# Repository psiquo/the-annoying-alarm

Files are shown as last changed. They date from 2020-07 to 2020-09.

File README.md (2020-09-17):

# The Annoying Alarm
The annoying alarm è una sveglia "intelligente" che una volta attivata si muove evitando gli ostacoli fino a quando non viene catturata e spenta.

L'orario della sveglia viene selzionata dall'utente mediante interfaccia web o mediante MQTT.

## Materiale utilizzato
- Arduino Mega
- Esp8266
- Active Buzzer
- 2x Powerbank
- 3x HC-SR04 
- L298N
- Bottone
- Set Macchina (Comprensivo di struttura e due motori DC)
- Batteria 9V

## Liberie Utilizzate
- [L298N](https://github.com/AndreaLombardo/L298N)
- [ESP8266Wifi](https://arduino-esp8266.readthedocs.io/en/latest/esp8266wifi/readme.html)
- [NTPClient](https://github.com/arduino-libraries/NTPClient)
- [Arduino-PID-Library](https://github.com/br3ttb/Arduino-PID-Library/)
- [WiFiUDP](https://github.com/esp8266/Arduino/blob/master/libraries/ESP8266WiFi/src/WiFiUdp.h)
- [Timezone](https://github.com/JChristensen/Timezone)
- [PubSubClient](https://github.com/knolleary/pubsubclient/)

## Circuito
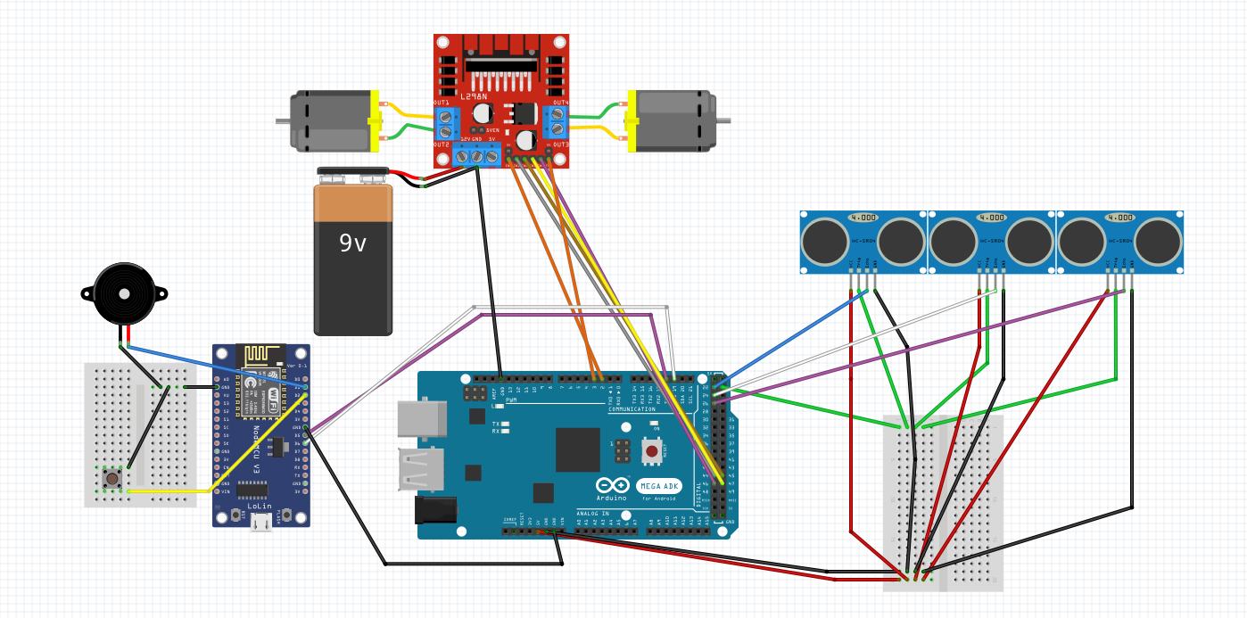
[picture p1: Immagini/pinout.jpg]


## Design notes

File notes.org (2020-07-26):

* Inbox
* Cablaggi
 - Rosso => Volt
 - Nero => Ground
 - Verde => Trigger
 - Blu => Echo Centrale
 - Viola => Echo Destra
 - Violetto => En2 Motore destro
 - Bianco => Echo Sinistra
 - Giallo => En1 Motore Sinistro
 - Blu => En2 Motore Sinistro
 - Grigio => En1 Motore Destro
 - Arancione => Enab Motori
* Pin Map
 - D0 => Trigger (OUT)
 - D1 => Echo centrale (IN)
 - D2 => Echo Destra (IN)
 - D3 => En2 Motore destro (se a 1 mentre en1 0 va in retro) (OUT)
 - D4 => Echo sinistra (IN)
 - D5 => En1 Motore sinistro (se a 1 mentre en 2 0 va avanti) (OUT)
 - D6 => En2 motore sinistro (tale quale D3) (OUT)
 - D7 => En1 motore destro (tale quale D5) (OUT)
 - D4 => Interrupt (si spera)

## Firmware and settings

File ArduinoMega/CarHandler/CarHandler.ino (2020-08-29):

#include "Constants.h"

bool led = true;
int target;

void setup() {
  // put your setup code here, to run once:
  pinMode(LED_BUILTIN,OUTPUT);
  setup_dist();
  setup_motor();
  setup_serial();
  Serial.begin(115200);
}

void loop() {
  handle_serial();
  if (enabled){
    drive();
  } else {
     motor_stop();
  }
}

void drive() {
    update_dist();
    dist = distance[1];
    fw_pid.Compute();
    go();
        
    if ( distance[1] < FORWARD_DISTANCE  and min(distance[0], distance[2]) > FORWARD_DISTANCE){
      motor_stop();
      if (distance[0] > distance[2]){
        target = distance[0];
        left(ROTATION_SPEED);
      } else {
        target = distance[2];
        right(ROTATION_SPEED);
      }
      do {
        update_dist();
      }while(distance[1] < max(target,30));
  
      motor_stop();
    } else if (distance[0] < SIDE_DISTANCE) {
      right(ROTATION_SPEED);
      do {
        update_dist();
      }while(distance[0] < max(30,distance[1]));
  
      motor_stop();
    } else if (distance[2] < SIDE_DISTANCE) {
      left(ROTATION_SPEED);
      do {
        update_dist();
      }while(distance[2] < max(distance[1],30));
    }
  }

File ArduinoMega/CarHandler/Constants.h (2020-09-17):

// Distance Module
//---Includes
#include <stdlib.h>
// --- Pins
/*const int*/ #define trigPin 23
const int echo[] = {22,24,26};

// --- Values
const int sensors = 3;
const int default_d_value = 200;
long duration;
double distance[sensors];
int tempDist;
double oldDistance[sensors];
int measures = 4;

//Motor Module
//---Includes
#include "L298N.h"
#include <PID_v1.h>
//---Pins
/* const int */ #define LEnab  2
/* const int */ #define REnab  3
/* const int */ #define LIn1 44
/* const int */ #define LIn2 45
/* const int */ #define RIn1 46
/* const int */ #define RIn2 47

//---Values
#define MAX_SPEED 200
#define MIN_SPEED 90//130
#define ROTATION_SPEED 90

#define FORWARD_DISTANCE 20
#define SIDE_DISTANCE 20

#define Kp 1.6//2.
#define Ki 9.6
#define Kd 0.//02

double dist,setPoint_fw = 70, output_speed=0;

L298N Left(LEnab, LIn1, LIn2);
L298N Right(REnab,RIn1,RIn2);

PID fw_pid(&dist, &output_speed, &setPoint_fw, Kp,Ki,Kd,REVERSE);

//Serial Module
//---Values
bool enabled = false;

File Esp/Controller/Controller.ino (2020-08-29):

#include "Constants.h"

bool led = true;

void log_msg(String msg) {
  Serial.println(msg);
  mqtt_print(msg);
}

void setup() {
  // put your setup code here, to run once:
  Serial.begin(115200);
  pinMode(LED_BUILTIN,OUTPUT);
  setup_wifi();
  setup_time();
  setup_alarm();
  setup_mqtt();
  setup_serial();
  setup_http();
}

void loop() {
  // put your main code here, to run repeatedly:
  mqtt_handle();
  check_alarm();
  handle_serial();
  if(alarm_active) {
    digitalWrite(alarmPin,HIGH);
  } else {    
    digitalWrite(alarmPin,LOW);
  }
  digitalWrite(LED_BUILTIN,led = not led);
  delay(1000);
}

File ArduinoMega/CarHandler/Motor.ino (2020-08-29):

void setup_motor() {
   pinMode(REnab,OUTPUT);
  pinMode(LEnab,OUTPUT);
  pinMode(LIn1, OUTPUT);
  pinMode(LIn2, OUTPUT);
  pinMode(RIn1, OUTPUT);
  pinMode(RIn1, OUTPUT);

  fw_pid.SetOutputLimits(MIN_SPEED,MAX_SPEED);
  fw_pid.SetMode(AUTOMATIC);
  fw_pid.SetSampleTime(20);
  
}

void set_speed(double speed_val){
  Left.setSpeed(speed_val);
  Right.setSpeed(min(speed_val + 50,255));
}

void go() {
  set_speed(output_speed); 

  Left.forward();
  Right.forward();
}

void left(double speed_val){
   set_speed(speed_val);

   Left.backward();
   Right.forward();
}


void right(double speed_val){
   set_speed(speed_val);

   Left.forward();
   Right.backward();
}

void motor_stop(){
  Left.stop();
  Right.stop();
}

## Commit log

2020-08-25 aggiunti moduli esp,mega e sito web
    [Pinout.fzz]
2020-08-29 Aggiunto controllo PID velocità motori, inserito print di informazioni via seriale e mqtt per esp
    [Pinout.fzz]
2020-09-17 Rimpiazzati pin da const int a define e completato schema fritzing
    [Pinout.fzz, Scheme.fzz]
2020-09-17 Sistemato README e aggiunta immagine circuito
    [Pinout.fzz]
